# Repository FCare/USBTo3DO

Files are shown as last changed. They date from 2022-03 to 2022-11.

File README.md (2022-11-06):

# USBTo3DO
Connecting USB controller to the 3do

## Goal of the project
Plug a set of modern controllers to an original 3DO to emulate D-Pad, FlightStick and mouse.
Still support original 3DO controllers using daisy chain.

## License
The full project is delivered under MIT License.
You can fork, build, even sell this if you wants to.

## Need more info
I may organize some batches for interested users which can not build it themselves.
If you are interested, you can mail to usb23do@gmail.com
Be sure that you can have one the controller listed here. Adding more controller is not guaranteed.

## Supported controllers
 - **D-Pad**
	 - Any HID Gamepad/joystick class device shall work with a default mapping.
	 - Xbox360 wired controllers is supported.
	 - Xbox360 wireless controller is supported using a USB wireless adapter (https://aliexpress.com/item/1005004013649915.html)
	  > As button layout is not standard, a [specific mapper can be implemented](#dedicated_mapping).
 - **Mouse**
	 - Any USB mouse with an HID descriptor might work as mouse.
 - **FlightStick**
	  > As there is no way from the HID decriptor to determine if a controler is a flightstick or a standard controler, a [specific mapper has to be implemented](#dedicated_mapping)
 - **Wheel**
	  > Even if 3DO did not get any wheel controller, USB23DO support some controler as wheel (no throttle), mostly for Need For speed game. This support requires a [specific mapper to be implemented](#dedicated_mapping)

## List of tested USB controllers
 - **D-Pad**
   - Sixaxis PS3 controller (Wired) (https://en.wikipedia.org/wiki/Sixaxis)
   - DualShock4 PS4 controller (Wired) (https://fr.wikipedia.org/wiki/DualShock)
   - Xbox 360 wirless controllers using a USB PC receiver (https://aliexpress.com/item/1005004013649915.html)
   - 8BitDo M30 controller (https://www.8bitdo.com/m30/)
   - Retrobit Saturn controller (https://retro-bit.com/sega-collaboration/#saturn2-4)
   - Classical WII controllers with USB adapter (https://www.mayflash.com/product/showproduct.php?id=21)
   - Orignial sega saturn controller with adapter (https://www.mayflash.com/product/showproduct.php?id=20)
   - Known issues on 8bitDo USB wireless adapter2, Logitech gamepad F310 and 8bitDo SN30 pro (https://www.8bitdo.com/sn30-pro-usb-gamepad/)
 - **Mouse**
   - a large set of USB mouse
 - **FlightStick**
   - Thrustmaster T-Flight Hotas X (https://shop.thrustmaster.com/fr_fr/t-flight-hotas-x.html)
   - Thrustmaster T-Flight Stick X (https://www.thrustmaster.com/fr-fr/products/t-flight-stick-x)
   - Logitech Extreme 3D Pro (https://www.logitechg.com/fr-fr/products/space/extreme-3d-pro-joystick.942-000031.html)
 - **Wheel**
   - Thrustmaster T80 (https://www.thrustmaster.com/fr-fr/products/t80-ferrari-488-gtb-edition)
 
As of today, it does not support USB HUB. So if you are using a wired controller, you will need an adapter per wired controller. When you plug a USB adpater able to handle multiple controller (like wii adapater, saturn adapter or Xbox360 wireless receiver), then you can connect multiples controllers.

In case you installed the daisy chain connector, you can plug other USB adaptors or original controllers, Daisy chain will work.

## Videos
- [**D-Pad**](https://www.youtube.com/watch?v=yVEVkbPncLI&t=19)
- [**Mouse**](https://www.youtube.com/watch?v=dmMzbSZ1rbM&t=14)
- [**FlightStick**](https://www.youtube.com/watch?v=JpNO-n8_HC8&t=34)
- [**Wheel**](https://www.youtube.com/watch?v=EjhhHNndm9Q)

## What is required
 - PCB as provided in this git project. (You can order to shops like [JLCPCB](https://jlcpcb.com) using the [gerber files provided](https://github.com/FCare/USBTo3DO/blob/release/PCB/Gerber/USB23DO_2022-11-05.zip)
 - One femelle DB9 connector (to connect to the 3do or to the previous controller)
 - One male DB9 (optional) to continue the controller daisy chain
 - One Waveshare rp2040 zero (https://www.waveshare.com/rp2040-zero.htm)
 - a 4 way level shihter (https://aliexpress.com/item/32771873030.html)
 - a 4.7uF - 10v capacitor
 - a DB9 cable extension (https://aliexpress.com/item/4000095438635.html)

Here is a picture of the v1.1 PCB:  

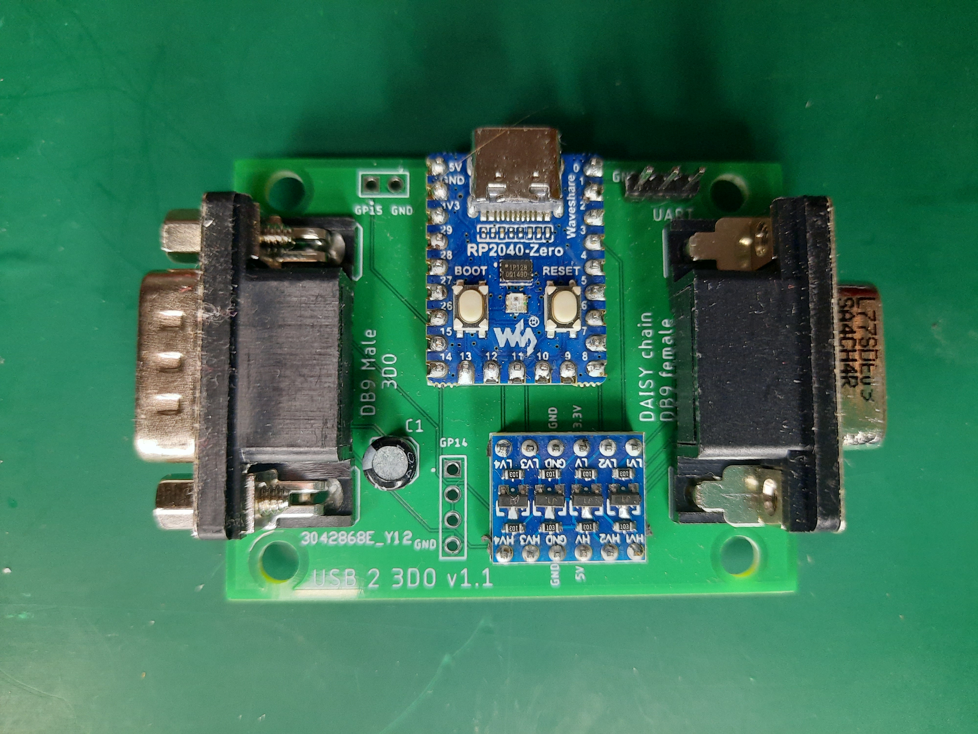
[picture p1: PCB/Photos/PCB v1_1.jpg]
PCB V1.1 PCB v1.1


## How to add a dedicated mapping
In order to add a specific mapping, you have to edit hid_gamepad.c or vendor_gamepad.c and add in the map array the VID, PID and corresponding mapping function. Once this is done, you have to compile a new FW and update the RP2040 device.

## How to compile
 - Tested on UBUNTU 20.04

 `git clone https://github.com/FCare/USBTo3DO.git`  
 `cd USBTo3DO`  
 `git submodule update --init --recursive`  
 `mkdir build;cd build`  
 `cmake ../`  
 `make -j16`  
 
 then flash RP2040 with the built uf2 file.

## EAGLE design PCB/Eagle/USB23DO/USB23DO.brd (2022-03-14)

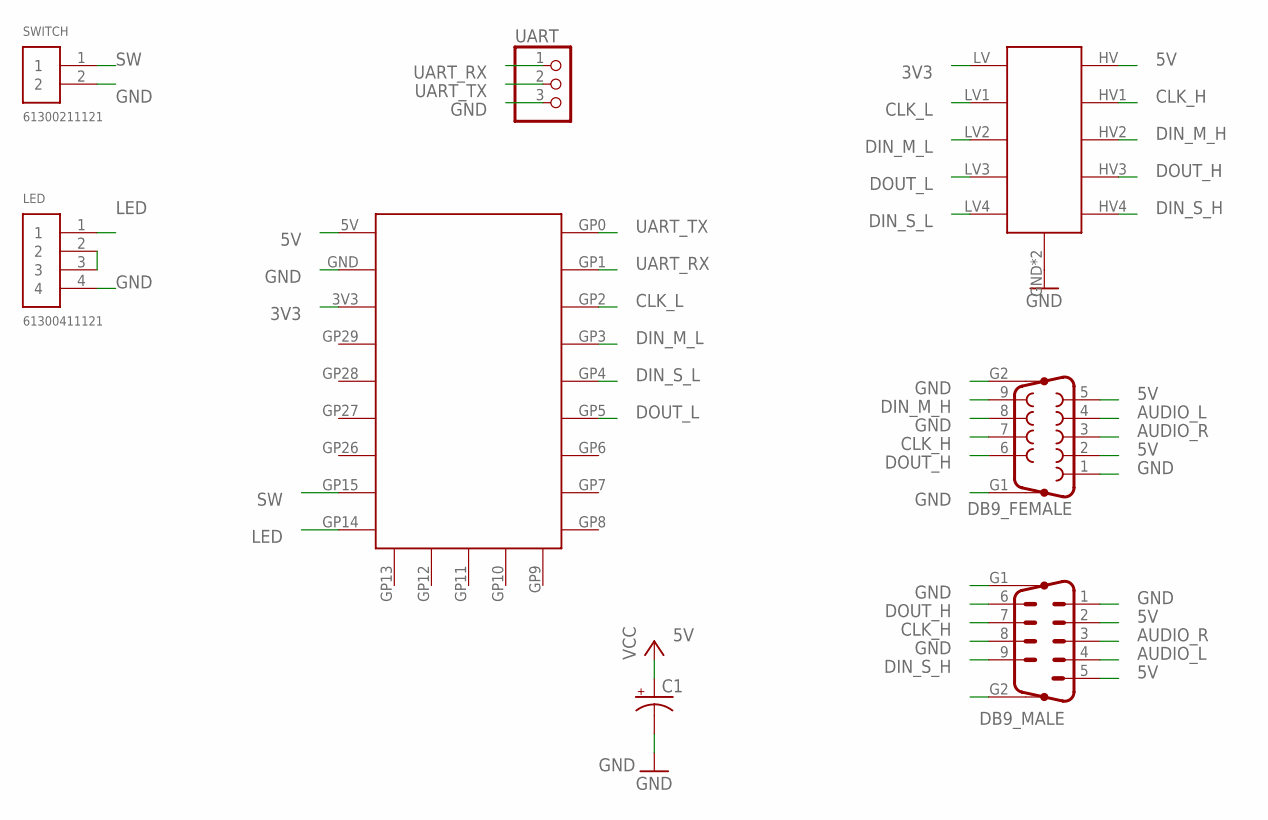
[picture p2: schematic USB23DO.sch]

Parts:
C1: CPOL-USB45181A; B45181A
DB9_FEMALE: F09HP
DB9_MALE: M09HP
LED: 61300411121
LVL_SHIFTER: 4WAYS_LEVEL_SHIFTER
RP2040-ZERO: WAVESHARE_RP_2040_ZERO
SWITCH: 61300211121
UART: PINHD-1X3CB; 1X03-CLEANBIG

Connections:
3V3: LVL_SHIFTER.LV, RP2040-ZERO.3V3
5V: C1.+, DB9_FEMALE.2, DB9_FEMALE.5, DB9_MALE.2, DB9_MALE.5, LVL_SHIFTER.HV, RP2040-ZERO.5V
AUDIO_L: DB9_FEMALE.4, DB9_MALE.4
AUDIO_R: DB9_FEMALE.3, DB9_MALE.3
CLK_H: DB9_FEMALE.7, DB9_MALE.7, LVL_SHIFTER.HV1
CLK_L: LVL_SHIFTER.LV1, RP2040-ZERO.GP2
DIN_M_H: DB9_FEMALE.9, LVL_SHIFTER.HV2
DIN_M_L: LVL_SHIFTER.LV2, RP2040-ZERO.GP3
DIN_S_H: DB9_MALE.9, LVL_SHIFTER.HV4
DIN_S_L: LVL_SHIFTER.LV4, RP2040-ZERO.GP4
DOUT_H: DB9_FEMALE.6, DB9_MALE.6, LVL_SHIFTER.HV3
DOUT_L: LVL_SHIFTER.LV3, RP2040-ZERO.GP5
GND: C1.-, DB9_FEMALE.1, DB9_FEMALE.8, DB9_FEMALE.G1, DB9_FEMALE.G2, DB9_MALE.1, DB9_MALE.8, DB9_MALE.G1, LED.4, LVL_SHIFTER.GND, LVL_SHIFTER.GND_1 (GND), RP2040-ZERO.GND, SWITCH.2, UART.3
LED: LED.1, RP2040-ZERO.GP14
unnamed: LED.2, LED.3
SW: RP2040-ZERO.GP15, SWITCH.1
UART_RX: RP2040-ZERO.GP1, UART.1
UART_TX: RP2040-ZERO.GP0, UART.2

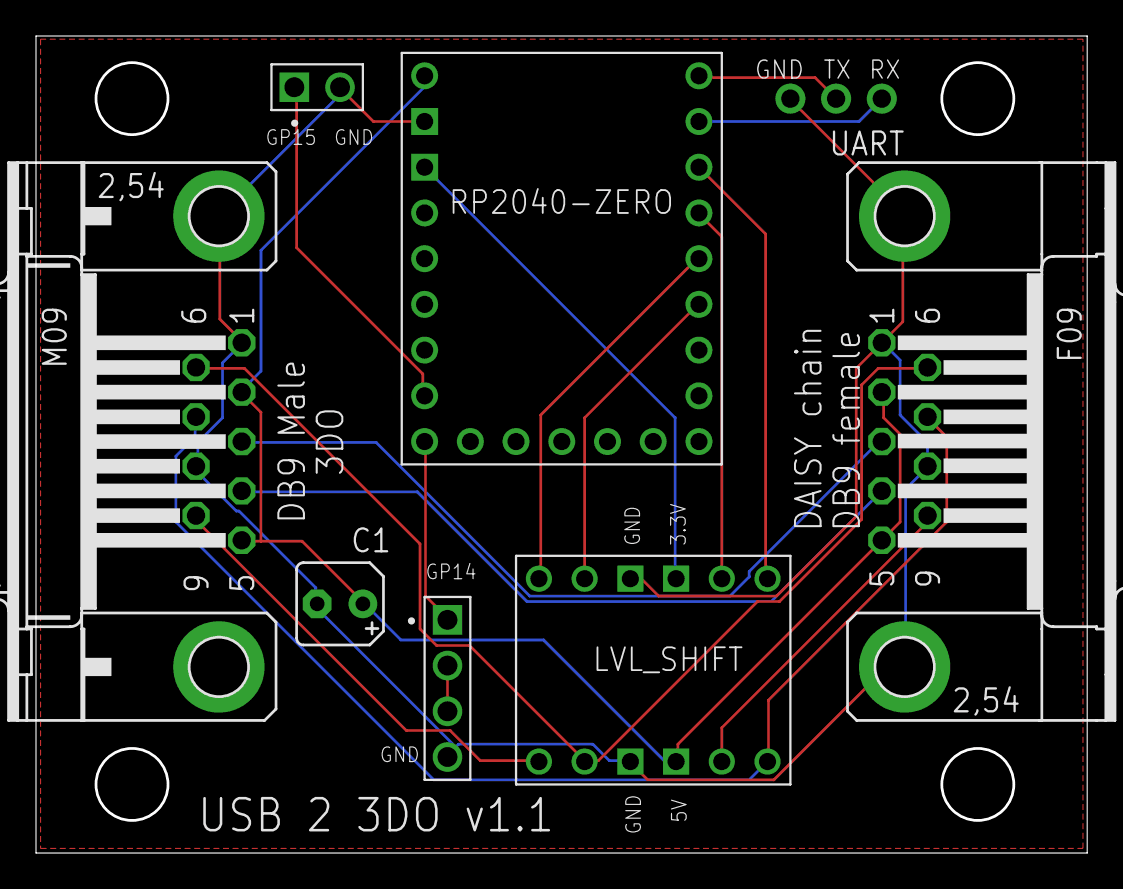
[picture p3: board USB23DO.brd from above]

Board: 2 copper layers, 58.4 x 45.4 mm, 8 parts (0 on the bottom side), 18 nets.

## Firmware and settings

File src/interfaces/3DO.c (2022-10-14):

#include <stdio.h>
#include <string.h>
#include "pico/stdlib.h"
#include "hardware/dma.h"
#include "hardware/structs/bus_ctrl.h"
#include "hardware/gpio.h"
#include "hardware/irq.h"
#include "pico/multicore.h"
#include "sampling.pio.h"
#include "output.pio.h"

#include "3DO.h"
#include "tusb.h"

//Missing dynammic allocation of controllers

uint sm_sampling = 0;
uint sm_output = 0;


uint16_t transmitReport[MAX_CONTROLERS]; //Only one controller at a time for the moment
uint8_t nbBits = 0;
uint8_t nbExternalBits = 0;

volatile bool updateReport = false;
uint8_t currentReport[MAX_CONTROLERS][9] = {0xFF};
uint8_t currentReportSize[MAX_CONTROLERS] = {0};
volatile bool deviceAttached[MAX_CONTROLERS] = {false};
volatile bool deviceReported[MAX_CONTROLERS] = {false};
volatile uint8_t externalControllerId = MAX_CONTROLERS;

enum {
  LEVEL_LOW  = (1<<0),
  LEVEL_HIGH = (1<<1),
  EDGE_FALL  = (1<<2),
  EDGE_RISE  = (1<<3)
} gpioMode;


typedef enum {
  CHAN_OUTPUT = 0,
  CHAN_INPUT,
  CHAN_MAX
} DMA_chan_t;

int channel[CHAN_MAX];
uint instr_jmp[CHAN_MAX];

uint max_usb_controller = 0;

dma_channel_config config[CHAN_MAX];

uint8_t controler_buffer[201] = {0xFF};


void startDMA(uint8_t access, uint8_t *buffer, uint32_t nbWord) {
  if (access == CHAN_OUTPUT)
    dma_channel_transfer_from_buffer_now(channel[access], buffer, nbWord);
  if (access == CHAN_INPUT)
    dma_channel_transfer_to_buffer_now(channel[access], buffer, nbWord);
}

void setupDMAOutput() {
  channel[CHAN_OUTPUT] = dma_claim_unused_channel(true);
  config[CHAN_OUTPUT] = dma_channel_get_default_config(channel[CHAN_OUTPUT]);
  channel_config_set_transfer_data_size(&config[CHAN_OUTPUT], DMA_SIZE_8);
  channel_config_set_read_increment(&config[CHAN_OUTPUT], true);
  channel_config_set_write_increment(&config[CHAN_OUTPUT], false);
  channel_config_set_irq_quiet(&config[CHAN_OUTPUT], true);
  channel_config_set_dreq(&config[CHAN_OUTPUT], DREQ_PIO0_TX0 + CHAN_OUTPUT);
  dma_channel_set_write_addr(channel[CHAN_OUTPUT], &pio0->txf[CHAN_OUTPUT], false);
  dma_channel_set_config(channel[CHAN_OUTPUT], &config[CHAN_OUTPUT], false);

  bus_ctrl_hw->priority = BUSCTRL_BUS_PRIORITY_DMA_W_BITS | BUSCTRL_BUS_PRIORITY_DMA_R_BITS;
}

void setupDMAInput() {
  channel[CHAN_INPUT] = dma_claim_unused_channel(true);
  config[CHAN_INPUT] = dma_channel_get_default_config(channel[CHAN_INPUT]);
  channel_config_set_transfer_data_size(&config[CHAN_INPUT], DMA_SIZE_8);
  channel_config_set_read_increment(&config[CHAN_INPUT], false);
  channel_config_set_write_increment(&config[CHAN_INPUT], true);
  channel_config_set_irq_quiet(&config[CHAN_INPUT], true);
  channel_config_set_dreq(&config[CHAN_INPUT], DREQ_PIO0_RX0 + CHAN_OUTPUT);
  dma_channel_set_read_addr(channel[CHAN_INPUT], &pio0->rxf[CHAN_OUTPUT], false);
  dma_channel_set_config(channel[CHAN_INPUT], &config[CHAN_INPUT], false);

  bus_ctrl_hw->priority = BUSCTRL_BUS_PRIORITY_DMA_W_BITS | BUSCTRL_BUS_PRIORITY_DMA_R_BITS;
}

// print_dma_ctrl(dma_channel_hw_addr(channel[CHAN_INPUT]));
void print_dma_ctrl(dma_channel_hw_t *channel) {
    uint32_t ctrl = channel->ctrl_trig;
    int rgsz = (ctrl & DMA_CH0_CTRL_TRIG_RING_SIZE_BITS) >> DMA_CH0_CTRL_TRIG_RING_SIZE_LSB;
    printf("(%08x) ber %d rer %d wer %d busy %d trq %d cto %d rgsl %d rgsz %d inw %d inr %d sz %d hip %d en %d\n",
           (uint) ctrl,
           ctrl & DMA_CH0_CTRL_TRIG_AHB_ERROR_BITS ? 1 : 0,
           ctrl & DMA_CH0_CTRL_TRIG_READ_ERROR_BITS ? 1 : 0,
           ctrl & DMA_CH0_CTRL_TRIG_WRITE_ERROR_BITS ? 1 : 0,
           ctrl & DMA_CH0_CTRL_TRIG_BUSY_BITS ? 1 : 0,
           (int) ((ctrl & DMA_CH0_CTRL_TRIG_TREQ_SEL_BITS) >> DMA_CH0_CTRL_TRIG_TREQ_SEL_LSB),
           (int) ((ctrl & DMA_CH0_CTRL_TRIG_CHAIN_TO_BITS) >> DMA_CH0_CTRL_TRIG_CHAIN_TO_LSB),
           ctrl & DMA_CH0_CTRL_TRIG_RING_SEL_BITS ? 1 : 0,
           rgsz ? (1 << rgsz) : 0,
           ctrl & DMA_CH0_CTRL_TRIG_INCR_WRITE_BITS ? 1 : 0,
           ctrl & DMA_CH0_CTRL_TRIG_INCR_READ_BITS ? 1 : 0,
           1 << ((ctrl & DMA_CH0_CTRL_TRIG_DATA_SIZE_BITS) >> DMA_CH0_CTRL_TRIG_DATA_SIZE_LSB),
           ctrl & DMA_CH0_CTRL_TRIG_HIGH_PRIORITY_BITS ? 1 : 0,
           ctrl & DMA_CH0_CTRL_TRIG_EN_BITS ? 1 : 0);
}

void core1_entry() {
  while(1) {
    vendor_gamepad_tick();
    hid_gamepad_tick();
    sleep_ms(500);
  }
}

static void currentReportDone(uint8_t instance) {
  if (currentReport[instance][0] == 0x49) {
    //Mouse report - Clear relative displacement to avoid continuous move
    currentReport[instance][1] &= 0xF0;
    currentReport[instance][2] = 0x00;
    currentReport[instance][3] = 0x00;
  }
}

// pio0 interrupt handler
void on_pio0_irq() {
  updateReport = true;
  dma_channel_abort(channel[CHAN_OUTPUT]);
  dma_channel_abort(channel[CHAN_INPUT]);
  pio_sm_drain_tx_fifo(pio0, sm_output);
  while (!pio_sm_is_rx_fifo_empty(pio0, sm_output)) pio_sm_get(pio0, sm_output);
  pio_sm_restart(pio0, sm_output);
  pio_sm_exec(pio0, sm_output, instr_jmp[sm_output]);

  int totalReportSize = 0;
  for (int i = 0; i<max_usb_controller; i++) {
    memcpy(&controler_buffer[totalReportSize], &(currentReport[i][0]), currentReportSize[i]);
    currentReportDone(i);
    totalReportSize += currentReportSize[i];
  }
  startDMA(CHAN_OUTPUT, &controler_buffer[0], 201);
  pio_sm_set_enabled(pio0, sm_output, true);
  startDMA(CHAN_INPUT, &controler_buffer[totalReportSize], 201-totalReportSize);
  pio_interrupt_clear(pio0, 0);
  irq_clear(PIO0_IRQ_0);
}

void _3DO_init() {
  uint offset;
  stdio_init_all();
  gpio_init(CLK_PIN);
  gpio_set_dir(CLK_PIN, GPIO_IN); //Input

  pio_set_irq0_source_enabled(pio0, pis_interrupt0, true);
  irq_set_exclusive_handler(PIO0_IRQ_0, on_pio0_irq);
  irq_set_enabled(PIO0_IRQ_0, true);
  sm_sampling = CHAN_MAX;
  offset = pio_add_program(pio0, &sampling_program);
  sampling_program_init(pio0, sm_sampling, offset);
  sm_output = CHAN_OUTPUT;
  offset = pio_add_program(pio0, &output_program);
  output_program_init(pio0, sm_output, offset);

  instr_jmp[sm_output] = pio_encode_jmp(offset);
  setupDMAOutput();
  setupDMAInput();
  pio_gpio_init(pio0, DATA_IN_PIN);
  gpio_pull_up(DATA_IN_PIN);
  pio_sm_set_consecutive_pindirs(pio0, sm_output, DATA_IN_PIN, 1, false);
  pio_gpio_init(pio0, DATA_OUT_PIN);
  pio_sm_set_consecutive_pindirs(pio0, sm_output, DATA_OUT_PIN, 1, true);
  multicore_launch_core1(core1_entry);
}


void update_3do_joypad(_3do_joypad_report report, uint8_t instance) {
  if (instance >= MAX_CONTROLERS) return;
  memcpy(&(currentReport[instance][0]), &report, 2);
  currentReportSize[instance] = 2;
  deviceAttached[instance] = true;
  max_usb_controller = (max_usb_controller < (instance+1))?(instance+1):max_usb_controller;
}
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

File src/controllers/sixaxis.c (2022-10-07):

#include "bsp/board.h"

#include <stdlib.h>
#include <math.h>

#include "sixaxis.h"

struct sixaxis_led {
	uint8_t time_enabled; /* the total time the led is active (0xff means forever) */
	uint8_t duty_length;  /* how long a cycle is in deciseconds (0 means "really fast") */
	uint8_t enabled;
	uint8_t duty_off; /* % of duty_length the led is off (0xff means 100%) */
	uint8_t duty_on;  /* % of duty_length the led is on (0xff mean 100%) */
} __packed;

struct sixaxis_rumble {
	uint8_t padding;
	uint8_t right_duration; /* Right motor duration (0xff means forever) */
	uint8_t right_motor_on; /* Right (small) motor on/off, only supports values of 0 or 1 (off/on) */
	uint8_t left_duration;    /* Left motor duration (0xff means forever) */
	uint8_t left_motor_force; /* left (large) motor, supports force values from 0 to 255 */
} __packed;

struct sixaxis_output_report {
	struct sixaxis_rumble rumble;
	uint8_t padding[4];
	uint8_t leds_bitmap; /* bitmap of enabled LEDs: LED_1 = 0x02, LED_2 = 0x04, ... */
	struct sixaxis_led led[4];    /* LEDx at (4 - x) */
	struct sixaxis_led _reserved; /* LED5, not actually soldered */
} __packed;

union sixaxis_output_report_01 {
	struct sixaxis_output_report data;
	uint8_t buf[36];
};

bool map_sixaxis(uint8_t instance, uint8_t *id, controler_type *type, void **res, void *ctrl_v)
{
  hid_controller *ctrl =(hid_controller*)ctrl_v;
  _3do_joypad_report *result = malloc(sizeof(_3do_joypad_report));
  *result = new3doPadReport();
  *type = JOYPAD;
  *id = ctrl->index + instance;
  hid_buttons *btn = & ctrl->buttons[ctrl->index];

  result->up = btn->TOP2 || (btn->ABS_Y < 64);
  result->down = btn->BASE || (btn->ABS_Y > 192);
  result->left = btn->BASE2 || (btn->ABS_X < 64);
  result->right = btn->PINKIE || (btn->ABS_X > 192);
  result->X = btn->BASE7 || btn->TRIGGER;
  result->P = btn->TOP;
  result->A = btn->BASE10;
  result->B = btn->BASE9;
  result->C = btn->BASE8;
  result->L = btn->BASE5 || btn->BASE3;
  result->R = btn->BASE6 || btn->BASE4;

  if (ctrl->hasHat[ctrl->index]) {
    result->up |= btn->HAT_UP;
    result->down |= btn->HAT_DOWN;
    result->left |= btn->HAT_LEFT;
    result->right |= btn->HAT_RIGHT;
  }

  *res = (void *)(result);

  return true;
}

bool mount_sixaxis(uint8_t dev_addr, uint8_t instance) {
  //Need to send dedicated packet to start the controller
  uint8_t buffer[17];
  tuh_hid_get_report(dev_addr, instance, 0xF2, 0x3, &buffer[0], 17, NULL);
  tuh_hid_get_report(dev_addr, instance, 0xF2, 0x3, &buffer[0], 17, NULL);
  tuh_hid_get_report(dev_addr, instance, 0xF5, 0x3, &buffer[0], 8, NULL);

  //Set default report
  static const union sixaxis_output_report_01 default_report = {
  		.buf = {
  			0x01, 0xff, 0x00, 0xff, 0x00,
  			0x00, 0x00, 0x00, 0x00, 0x00,
  			0xff, 0x27, 0x10, 0x00, 0x32,
  			0xff, 0x27, 0x10, 0x00, 0x32,
  			0xff, 0x27, 0x10, 0x00, 0x32,
  			0xff, 0x27, 0x10, 0x00, 0x32,
  			0x00, 0x00, 0x00, 0x00, 0x00
  		}
  	};
  	struct sixaxis_output_report report;
  	int n;

  	/* Initialize the report with default values */
  	memcpy(&report, &default_report, sizeof(struct sixaxis_output_report));

  #ifdef CONFIG_SONY_FF
  	report.rumble.right_motor_on = sc->right ? 1 : 0;
  	report.rumble.left_motor_force = sc->left;
  #endif

  	report.leds_bitmap |= 0x1 << (instance+1);

  tuh_hid_set_report(dev_addr, instance, 0x1, 0x2, &report,sizeof(struct sixaxis_output_report));
  return true;
}

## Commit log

2022-03-13 Add support for 8bitDo, retrobit, Xbox360 wired and some other cheap USB controlers
    ignore pico-sdk modifications
    First drop of USB host
    Enable USB_HOst with Dualshock4 support
    Cleanup LCD code
    Add first gamepad reports for xbox 360 controllers
    Use personnal tinyUSB for xbox360 gamepad support
    Separate HID based gamepad and vendor specific gamepad
    Add button mapper for 8bitDo controller
    Set the pico board
    continue on HID report - right now no report callback...
    Update gameapad support
    fix 3do report - Too slow when based on GPIO. Have to move to SPI
    add missing files
    Cleanup - refacto
    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
    [3DO.c, 3DO.h]
2022-03-14 Add PCB files
    Zip can be used to order PCB on JLCPCB
    To edit, EAgle compatbile files are provided
    [USB23DO.brd, USB23DO.sch]
2022-03-14 Add v1.0 PCB photo
    This version has an issue with one of the DB9 connector and does not support extension like switch or led support.
2022-09-13 Add daisy chain suport on pio
2022-09-13 Immplement flight stick behavior on Xbox 360 controller. Need to press mode button to switch between stick and pad mode. X/D are mapped on left stick, Y is mapped on analog trigger. This is due to th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
2022-09-13 Add a tick for led animation on controllers
2022-09-13 Add an anlogic mode for flight and one for wheel. Switch on xbox360 is done by pressing mode button. Joypad->Flight->wheel mode
2022-09-13 Add Thrustmaster Hotas X suuport as flight stick
2022-09-13 Add Thrustmaster T80 steering wheel support as flight stick for need for speed
2022-09-15 Add x360 wired controller suupport
2022-09-29 Add an early HID parser to detect button mapping from HID descriptor
2022-11-05 Update PCB files to v1.1
2022-11-06 Fix T80 wheel
